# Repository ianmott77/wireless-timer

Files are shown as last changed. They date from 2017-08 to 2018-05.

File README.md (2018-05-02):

###### Author: Ian Mott

# Wireless Timer
This project aims at making a portable wireless timing system that's primary use is for athletics. The project's main sport of focus to start is alpine ski racing. 
 # Contents
 1. [Sports](#sports)
 2. [Features](#features)
 3. [Video](#video)
 4. [Things to know](#things-you-should-know-before-continuing-with-setup)
 5. [Hardware](#hardware)
 6. [Software](#software)
 7. [Usage](#using-the-wireless-timer)
 8. [Screenshots](#screenshots)
 
 # Sports
 ## Alpine Ski Racing
 In alpine ski racing a racer starts at the top of a race and goes through a wand which starts their time and the finish is triggered when the race crosses the "eyes" at the bottom. Finish eyes traditionally use some form of LASER or light break beam. During training sessions some teams will use wireless timing systems which can do this task with no wired set up required. This is a great training tool as it can tell you who is going fastest and when people are improving, and most teams who have them are able to see more improvements. One issue with current systems is they are expensive, some of them are outdated and haven't been upgraded in decades, and many of them are not very user friendly. That’s why this project was born! The goal is to use Arduino's and Raspberry Pi's to create a wireless timer which is cheaper and aims at usability.

# Features 
* Wireless Timing via LoRa line of site up to 20km
* Start and Finish currently, plans to support monitor tablet and multiple intervals
* Pace Mode and Stopwatch Mode
* Finish line length of up to 40m
* Virtually unlimited number of people on the track at one time
* Virtually unlimited space for runs
* Resistive touch screen to be able to provide a user-friendly UI while still allowing use of gloves or hand protection

# Video
Below is a link to a YouTube video demonstrating simple usage and proof of work for the idea:
* https://youtu.be/bO8R6ozuvQg

# Things You Should Know Before Continuing with Setup
* How to solder
* Basic C/C++ programming knowledge would be an asset (e.g. loops, constants)
* Basic Knowledge of Linux systems (e.g. file system, terminal use)
* How to upload Arduino libraries
* How to import new Arduino libraries

# Hardware
The idea behind the hardware set up is that the Arduino is used for sensors for the outside world while the Raspberry Pi (RPi) is responsible for handling the display as well as doing the information processing and storing information. 
## Set Up
### Hardware Needed
#### For All Pieces
* Raspberry Pi Zero W (https://www.raspberrypi.org/products/raspberry-pi-zero-w/)
* Arduino UNO (https://store.arduino.cc/usa/arduino-uno-rev3)
* Waveshare 4inch HDMI LCD, 800×480, IPS (https://www.waveshare.com/4inch-HDMI-LCD.htm)
* Adafruit RFM95W LoRa Radio Transceiver Breakout - 868 or 915 MHz (https://www.adafruit.com/product/3072)
* 4-channel I2C-safe Bi-directional Logic Level Converter (https://www.adafruit.com/product/757)
* MCP3008 - 8-Channel 10-Bit ADC With SPI Interface (https://www.adafruit.com/product/856)
* PowerBoost 1000 Charger - Rechargeable 5V Lipo USB Boost @ 1A - 1000C (https://www.adafruit.com/product/2465)
* Lithium Ion Battery Pack - 3.7V 6600mAh (https://www.adafruit.com/product/353)
* MicroSD Card
* 100k resistor
* Momentary push button 
* Yellow LED
* Red LED
* Blue LED
* 4 x 10k resistor
* 3 x 4001N diode
* 3 x 330 Ohm resistor
* 2 x 6.8k resistor

#### Interval Only
* LIDAR-Lite v3 (https://www.sparkfun.com/products/14032)

#### Starter Only
* Magnetic contact switch (https://www.adafruit.com/product/375)

### Diagrams
If you look in the diagrams folder you will find fritzing diagrams of how the different pieces need to be set up. The RPi and Arduino are connected through two different connections, the serial pins (UART) and I2C.

#### Starter Set Up
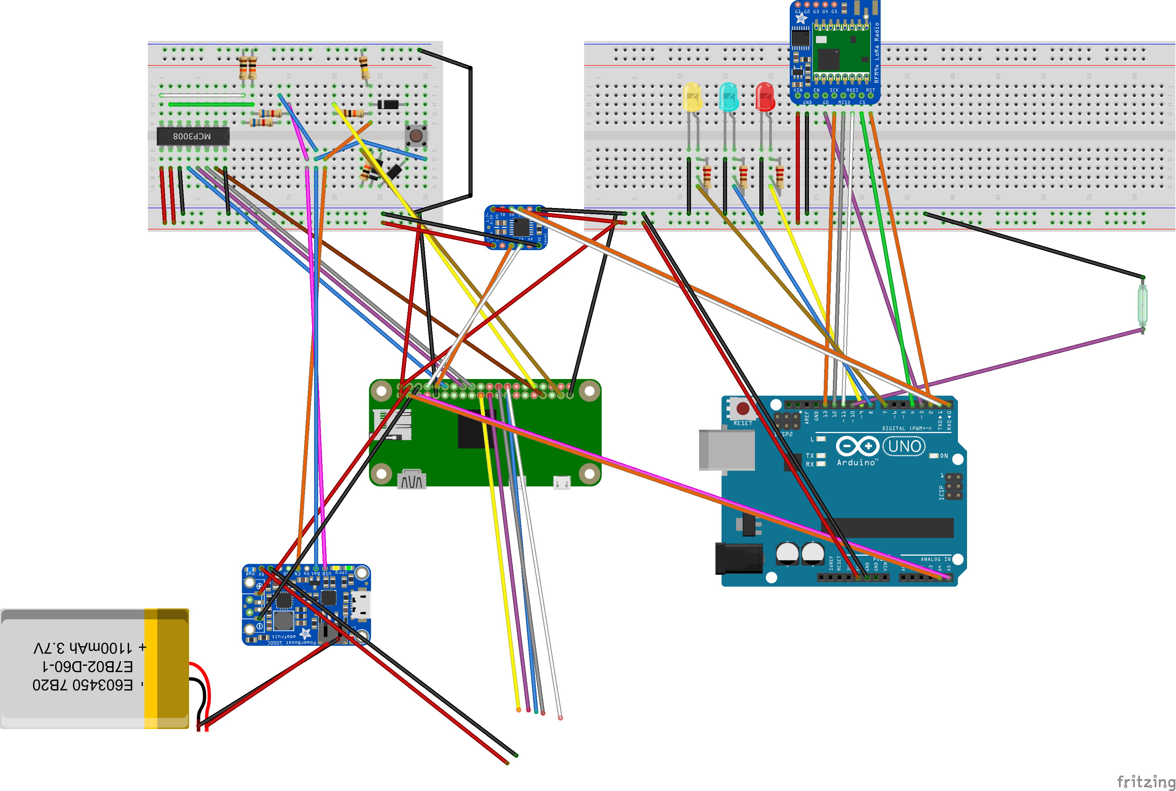
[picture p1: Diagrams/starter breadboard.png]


#### Finisher Set Up
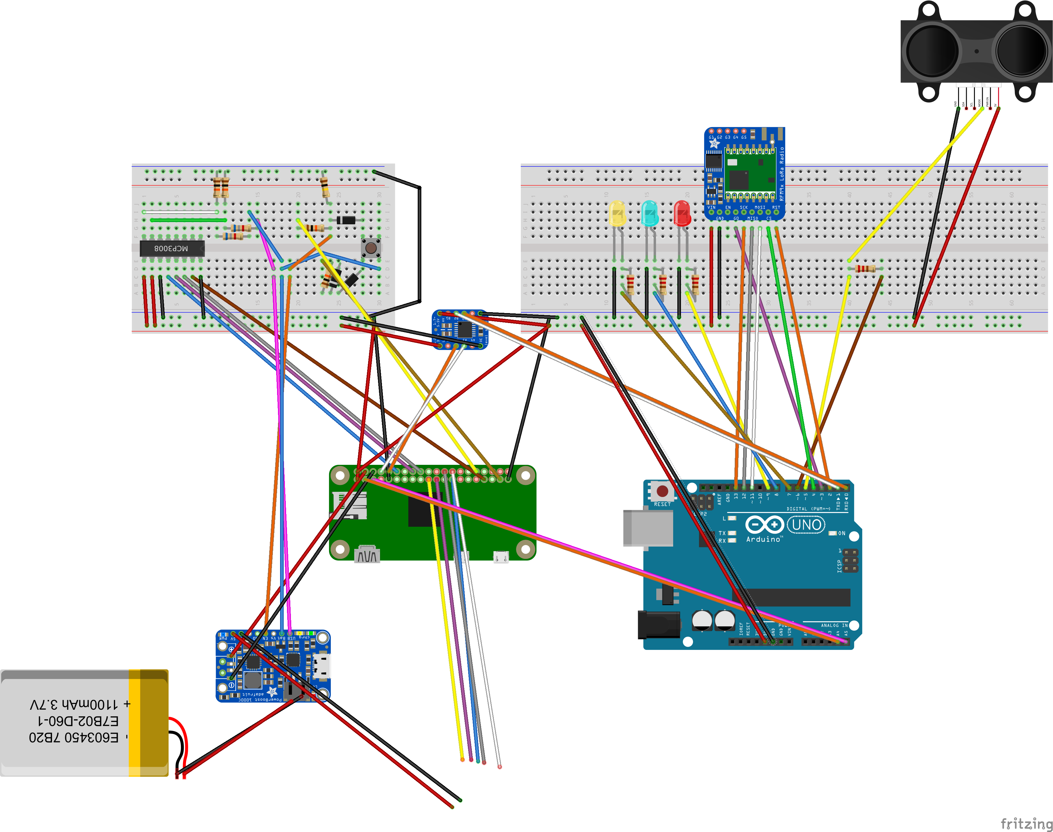
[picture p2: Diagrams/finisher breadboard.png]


##### Notes
* Where the wires disappear in the diagram is where they connect to a Waveshare 4" resistive touchscreen LCD
* In my set, up I used a 6600 mAH battery
* Yellow LED is the TX LED for the Arduino
* Blue LED is the RX LED for the Arduino
* Red LED is the error LED for the Arduino
* The LCD get's its own 5V power supply from the PowerBoost because it draws a large current and when it get's it's power from the rail on the breadboard I observed some flickering

# Software
## Repositories
All of them are required to run the WirelessTimer software, however for pi_power it is suggested that you use the script provided in this repository as it has been modified to accommodate the different battery voltage and different pins used.

### Raspberry Pi
* WirelessTimer: https://github.com/ianmott77/wireless-timer-rpi
* pi_power (modified): https://github.com/ianmott77/wireless-timer/blob/master/pi_power.py (Big thanks to @craic!! Original repo found here https://github.com/craic/pi_power)

### Arduino
* WirelessTimer: https://github.com/ianmott77/wireless-timer-arduino
* RadioHead: http://www.airspayce.com/mikem/arduino/RadioHead/
* LIDARLite V3: https://github.com/garmin/LIDARLite_v3_Arduino_Library

## Set Up
## Arduino
To set up the software for the Arduino start by downloading the WirelessTimer repo. The CLI folder contains the main program for the Arduino while the Connection folder contains the framework that it's built on. To install the program, add the Connection library, the RadioHead library and the LIDARLite V3 library to the Arduino software (instruction here: https://www.arduino.cc/en/hacking/libraries).

#### Device ID
Inside the repo you will also find a folder named "tools" inside this folder you will find a script name "WriteDeviceID" in order to set up the Arduino we need to write a Device ID to it's EEPROM which will be saved permanently and should be unique for all the timers in your network. If you open the script you will find a script like this
```
#include <EEPROM.h>
#define DEVICE_ID x

void setup(){
    EEPROM.write(0, DEVICE_ID);
}
void loop(){}
```
To write your desired unique device ID to the Arduino simply change where the "x" is to the unique device ID number you want and upload it to the Arduino. The device ID will be save permanently to the Arduino, after you run this script once you won't have to run it on an Arduino again unless you are changing its device type.

#### Device Type
Inside the repo you will also find a folder named "tools" inside this folder you will find a script name "WriteDeviceType" in order to set up the Arduino we need to write the device type to the Arduino. There are 3 different device types 

* 1 = Starter
* 2 = Interval (Finish Eyes)
* 3 = Monitor Node (not yet implemented)

```
#include <EEPROM.h>
#define DEVICE_TYPE x

void setup(){
    EEPROM.write(1, DEVICE_TYPE);
}
void loop(){}
```
To set the device type of the Arduino simply change the "x" in the script to the device type of you need and upload it to the Arduino. The device type will be save permanently to the Arduino, after you run this script once you won't have to run it on an Arduino again unless you are changing its device ID.

#### CLI
The final set up step for an Arduino is to upload the CLI script. Once you have done that the setup is complete. If everything is wired correctly you should see all three lights blink once, and nothing should be displayed on the serial monitor in the Arduino IDE if you have that open.

## Raspberry Pi
### Operating System
This project uses Raspbian Stretch Lite (https://www.raspberrypi.org/downloads/raspbian/) as it's base but requires several steps to set up. In future this will all be rolled in to a custom image but currently requires manual set up.
#### Configuring Raspbian
##### Downloading and setting up the MicroSD
To set up the Wireless timer software you first need to write the Raspbian Lite image to a micro SD card which is compatible with Raspberry Pi Zero W's (most micro SD's should work). If you're not sure how to do this, you can find detailed instructions here:

* https://www.raspberrypi.org/documentation/installation/installing-images/

To login the default username for the OS is "pi" and the default password is "raspberry"

#### Installing Display Drivers
The Waveshare screen should work with and HDMI connection from the RPi by default however the display may be the wrong orientation and it may be the wrong resolution, and the touch functionality won't work properly. You can follow the instructions found here:

* https://www.waveshare.com/wiki/4inch_HDMI_LCD

to setup the display properly. Once the drivers are installed you can test weather or not it is working with the program evtest. evtest is used to test input. It can be installed by typing```sudo apt-get install evtest``` and it can be run by typing ```evtest```. If you are not getting any input when touching the screen, check the connection and that you have the screen connected to the proper pins on the RPi.

#### Setting up pi_power
To set up pi power you can follow the instructions here however read bellow for the modifications made for this project:

* https://github.com/craic/pi_power

however, the script hosted in this repository is set up to use GPIO12 for boot up and GPIO13 to replace GPIO25, because GPIO25 is used by the touch screen, and the max and minimum voltages are adjusted for the battery I used.

In pi_power GPIO14 is used to power up the RPi because it goes high when booting up but goes low when powering down, however GPIO14 is the TX pin for the RPi and used by the Arduino to communicate. To accommodate this, we simulate GPIO12 going high when booting by using a custom device tree blob, detailed instructions on how to set this up can be found here: 

* https://www.raspberrypi.org/documentation/configuration/pin-configuration.md

to simulate GPIO12 going high when the RPi boot's we set it to output mode, and active. I have provided a dt-blob.dts in this repo which does that and should allow GPIO12 to be high after holding the momentary push button for a couple second and will go low when the RPi shuts down.

#### Setting up QT and EGLFS
Currently the only way to use this project is to build the WirelessTimer from scratch and currently the only host system tested so far is Ubuntu 17.10.

The Raspberry Pi portion of the project is based on QT. You can download QT for free here: 

* https://www.qt.io/download-qt-installer 

For the WirelessTimer program QT needs to be installed on the RPi's. Detailed instructions can be found here:

* https://wiki.qt.io/RaspberryPi2EGLFS

Note when setting up with a Raspberry Pi Zero or Zero W you will use the same compile commands as the Raspberry Pi 1. This process can take several hours so be patient and pay careful attention that you are doing the steps correctly. 

Once QT has been successfully installed the following QT modules also need to be installed:
* Qt Declarative (https://github.com/qt/qtdeclarative)
* Qt Quick Controls 2 (https://github.com/qt/qtquickcontrols2)
* Qt Quick Virtual Keyboard (https://github.com/qt/qtvirtualkeyboard) (not used currently but will be in future)

if you have followed all the instructions correctly you should have a kit setup where you can upload compiled Qt programs to your RPi.

# Using the Wireless Timer
If at any point you are not sure if you are on the right page you can refer to the screenshot section bellow to confirm.

### Import the project
To get started you first need to download the software here:
* https://github.com/ianmott77/wireless-timer-rpi
once it is downloaded you need to import it as project to Qt.

### Running the program
When the program runs you will notice the yellow and blue LED's blink frequently, this is because they blink every time there is an interaction either between the two Arduino's via LoRa or locally between the Arduino and the RPi. If the red LED blinks three times that means that is has hit an error, and which ever other LED is also lit while it's blinking indicates weather the error was while transmitting (yellow LED) or receiving (blue LED).

##### Setting the Finish
You will notice on interval pieces that the screen will automatically go the "Set Finish Distance" page. To set the distance, you simply click start and the LIDAR Lite will start measuring distances and reporting it back to the RPi. Point the LIDAR Lite at an object where you would like to line up your finish line and hit set. If you hit cancel if will set the distance to whatever it was set at last, if nothing was set then it will go back to 0.

#### Synchronizing Devices
On all device you will notice that there is a "Status" page. On the "Status" page you will see that there is both a "Position" and a "ID". The "Position" on all devices will default to 1, and the device ID of each device is set permanently by writing it to the EEPROM of the Arduino when you set it up. 

##### Position
Because the network is set up similarly to a doubly linked list(https://en.wikipedia.org/wiki/Doubly_linked_list), every device knows about the device that is at the position before it and the device that is at the next position. Because currently only a start and finish are supported there are only two positions that are relevant:
1: Start
2: Finish
and because currently you are always adding the finish from the start you always want the position you are adding to be 2.

##### Device ID
This is the device ID you specified when setting up the Arduino. This can be found on the status page of the finish device.

To synchronize the device, enter the position you want to add to the network (2) and the device ID of the device you want to add. For example, if I had a Start piece which had the ID=4, and a finish piece with the ID=9, on the "Add Device" page I would want to tap the text box I want to edit and for "Device Position:" I would enter 2, and for "Device ID" I would enter 9.

Once the sync is complete you will notice that in the status bar of both devices that the red circle next to "Sync:" are now green. This indicates that the sync was successful.

#### Selecting a Mode
The WirelessTimer software offers different modes in which to time, currently it offers stopwatch mode, and pace mode. On the "Mode Select Page" you will find a button for both options, and if you go to the "Options" page you will find a button "Select Mode" which allows you to return to the "Mode Select" page if you would like to switch from one mode to the other.

##### Stopwatch
This mode is the most basic mode in which to time. The times start as soon as the magnetic contact opens and will stop when something makes the LIDAR Lite pick up a distance less then 15cm of what the finish distance was set to. You also have the option to manually DNF (Did Not Finish) the racer as well if they won’t be completing the run. This mode allows for as many people on course as you would like and will not automatically DNF anyone.

##### Pace
In pace mode a reference time is used to determine weather or not something crossing the finish line is likely to be the thing we expect to be crossing the line. Currently the threshold to test against the pace time is 10 seconds. For example if you select pace mode the first person to go down the course will have their finish time recorded as the pace time, and from then on when someone starts the time any thing that triggers the finish which is 10 seconds faster than the pace time will not trigger the finish, and if the time goes more then 10 seconds over the pace time then the finish will automatically trigger a DNF.

#### Starting a racer
Once you know which mode you would like and select that button a keyboard will appear with a text box above it. The text box holds the bib number of the racer about to start and defaults to 1. If the start is not synchronized the "Okay" button will be grey and disabled, if it is green the it is ready to go!

##### Stopwatch Mode
In stopwatch mode it is very straight forward you simply enter a bib number, hit "Okay" and open the magnetic contact switch and the time will be started. You can do as many racers on the track at one time as you would like.

##### Pace Mode
In pace mode you will enter the number of the bib you would like to, hit "Okay", and then open the magnetic contact switch, however in pace mode if there is no pace time set then the start will stay with the "Ready!" page with a loading indicator bellow it until the racer completes there run, at which point the time of the racer will be transmitted back to the start, and from then on the pace will be set at the first runners time, and the threshold will be 10 seconds. If the person setting the pace does not complete their run you can manually click "DNF" on the finish piece which will let the start know that a pace wasn't set and then the next racer will set the pace.

# Screenshots
#### Mode Select
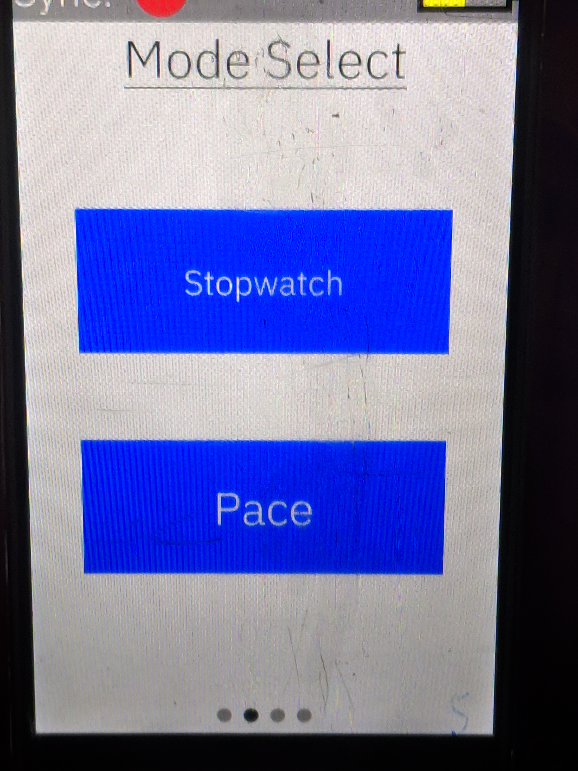
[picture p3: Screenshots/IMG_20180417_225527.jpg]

#### Set Finish Distance
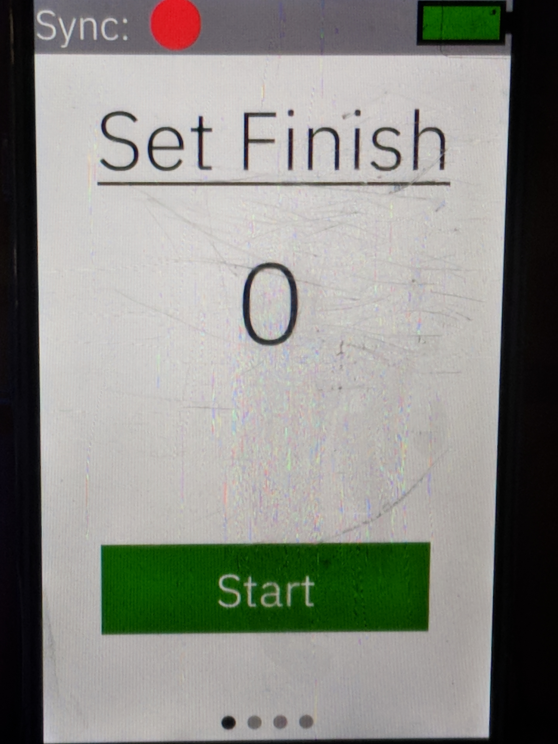
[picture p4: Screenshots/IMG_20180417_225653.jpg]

#### Choose Bib Number
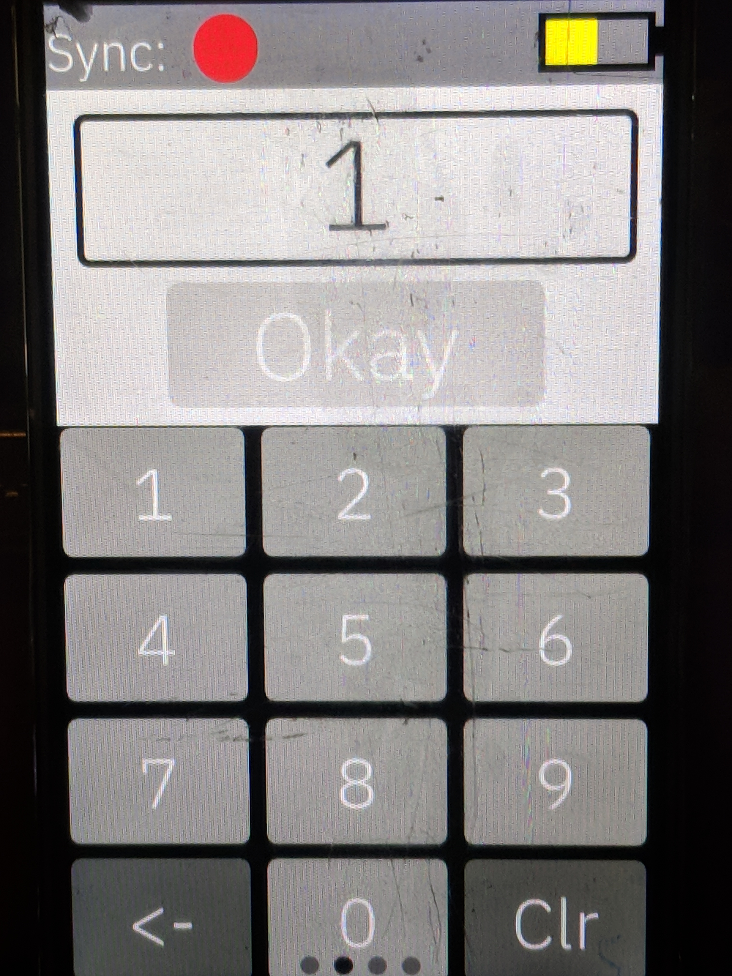
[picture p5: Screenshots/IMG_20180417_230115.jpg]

#### Status
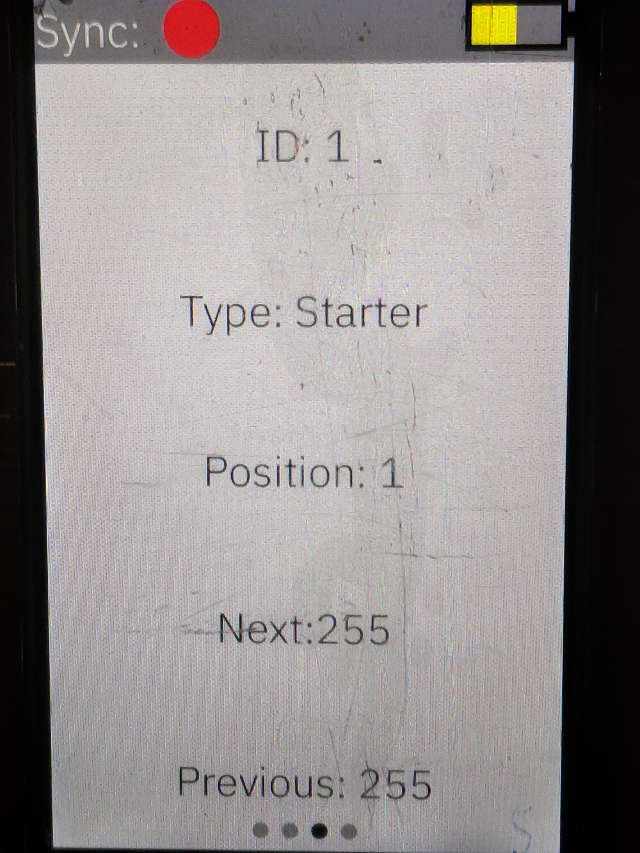
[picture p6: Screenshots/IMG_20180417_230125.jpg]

#### Add Device
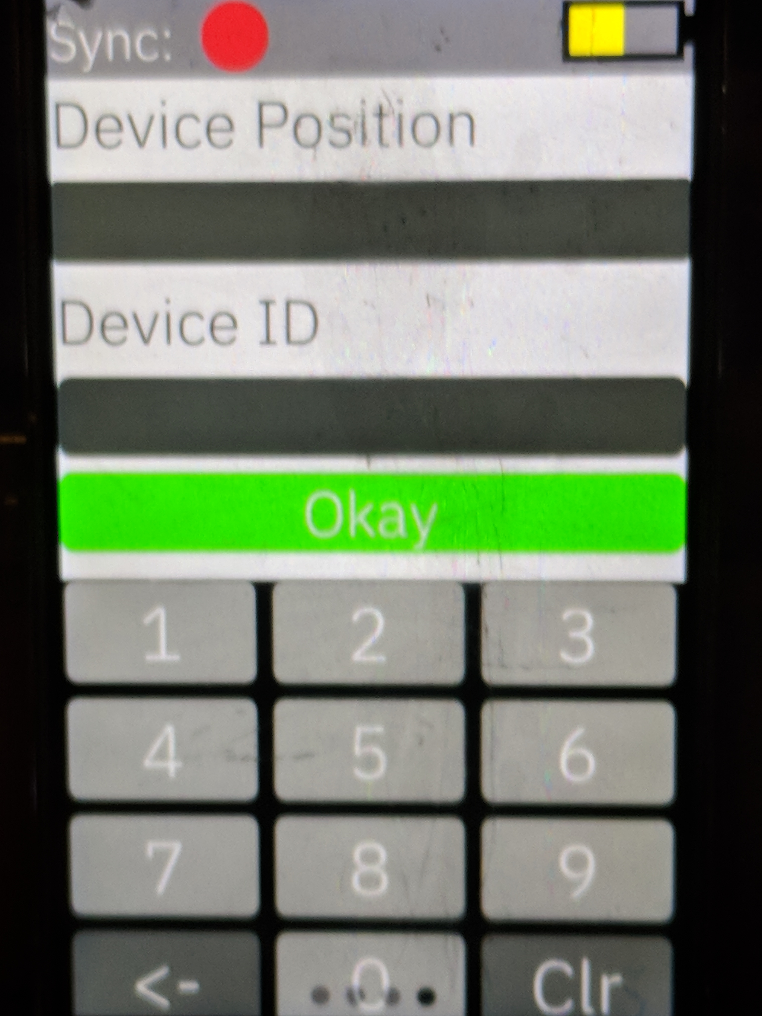
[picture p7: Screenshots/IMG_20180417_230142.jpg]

#### Options
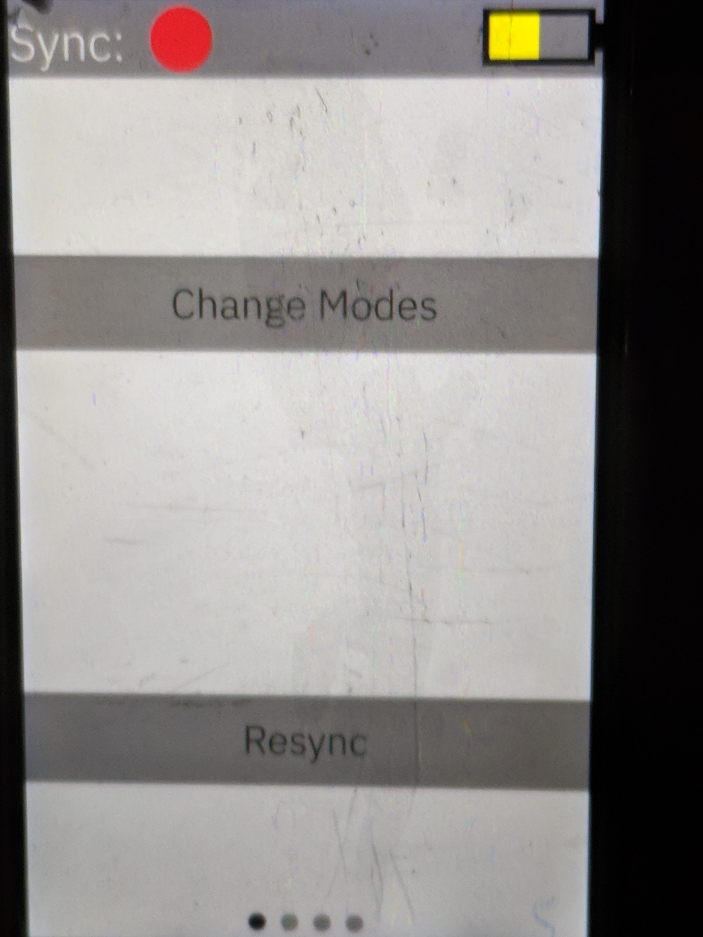
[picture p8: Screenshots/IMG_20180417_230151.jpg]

#### Time of Next to Finish
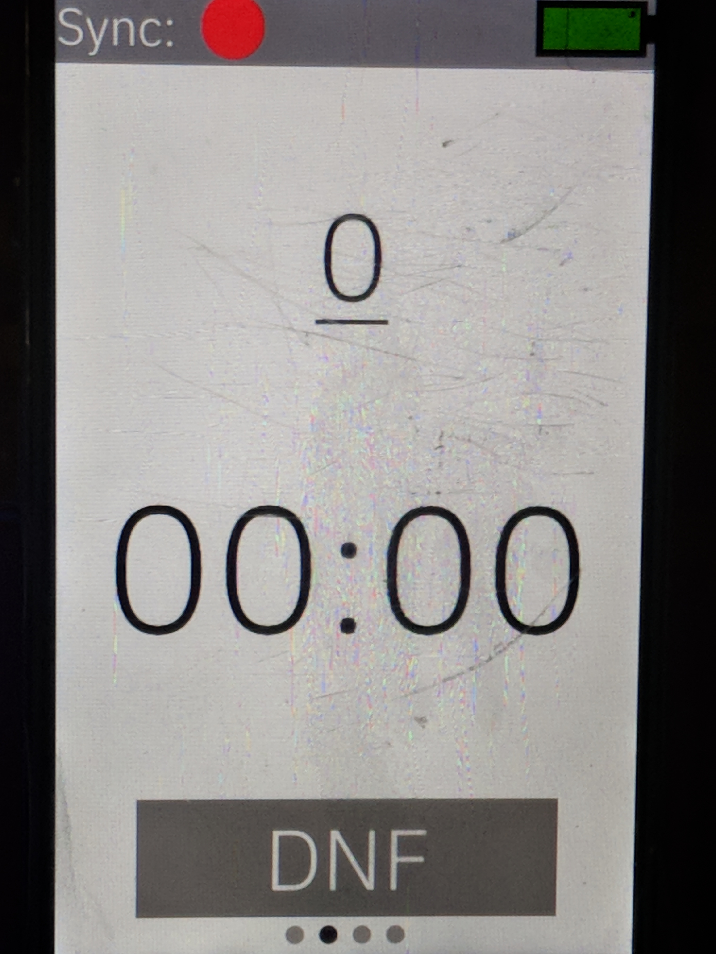
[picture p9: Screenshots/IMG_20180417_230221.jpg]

#### View All Times
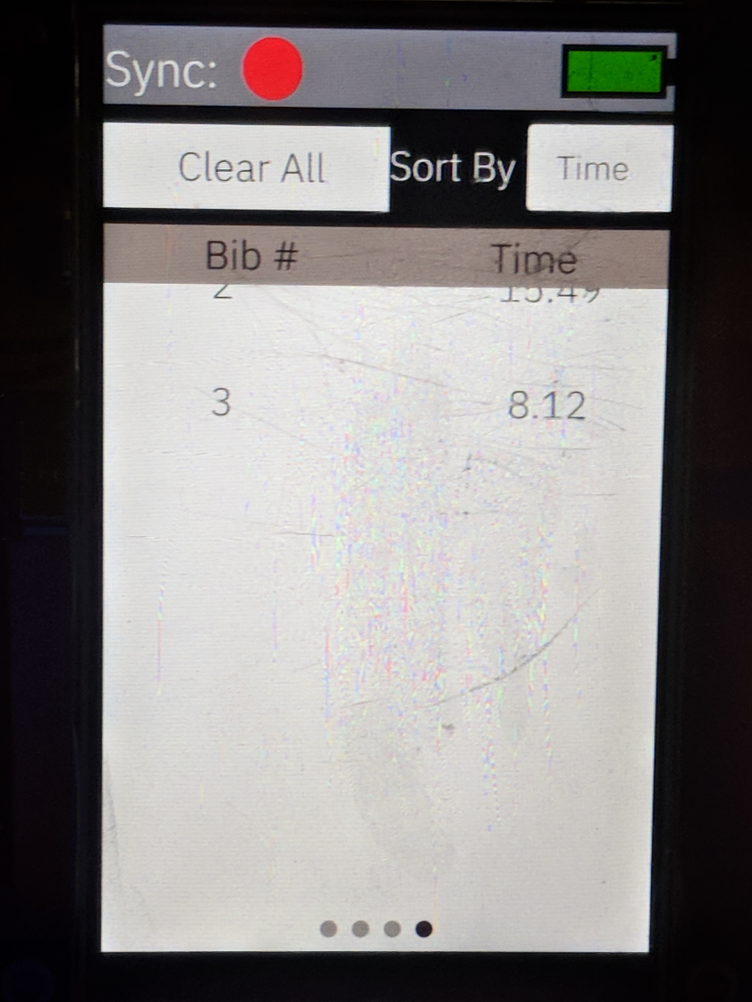
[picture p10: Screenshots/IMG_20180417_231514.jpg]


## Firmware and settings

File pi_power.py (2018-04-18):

#!/usr/bin/env python

# pi_power.py

# Robert Jones 2016 jones@craic.com

# The code for reading the MCP3008 analog to digital convertor (readadc) was
# written by Limor "Ladyada" Fried for Adafruit Industries, (c) 2015
# This code is released into the public domain


# Works with an Adafruit PowerBoost 1000C LiPo battery charger

# Writes the fraction of battery remaining as well as the current power source to the file /home/pi/.pi_power

# format:  <float 0.00 - 1.00>,<string [battery|usb]>
# 0.75,battery
# 1.00,usb



import time
import os
import argparse
import RPi.GPIO as GPIO


# read SPI data from MCP3008 chip, 8 possible adc's (0 thru 7)
def readadc(adcnum, clockpin, mosipin, misopin, cspin):
        if ((adcnum > 7) or (adcnum < 0)):
                return -1
        GPIO.output(cspin, True)

        GPIO.output(clockpin, False)  # start clock low
        GPIO.output(cspin, False)     # bring CS low

        commandout = adcnum
        commandout |= 0x18  # start bit + single-ended bit
        commandout <<= 3    # we only need to send 5 bits here
        for i in range(5):
                if (commandout & 0x80):
                        GPIO.output(mosipin, True)
                else:
                        GPIO.output(mosipin, False)
                commandout <<= 1
                GPIO.output(clockpin, True)
                GPIO.output(clockpin, False)

        adcout = 0
        # read in one empty bit, one null bit and 10 ADC bits
        for i in range(12):
                GPIO.output(clockpin, True)
                GPIO.output(clockpin, False)
                adcout <<= 1
                if (GPIO.input(misopin)):
                        adcout |= 0x1

        GPIO.output(cspin, True)
        
        adcout >>= 1       # first bit is 'null' so drop it
        return adcout


# Calculate the output of a voltage divider
# voltage_divider layout is:
# Vin ---[ R1 ]---[ R2 ]---GND
#               |
#              Vout
#
# Vout = R2 / (R1 + R2) * Vin
# e.g. if R1 = 6800 and R2 = 10000 and Vin is 5.2V then Vout is 3.095
#
def voltage_divider(r1, r2, vin):
        vout = vin * (r2 / (r1 + r2))
        return vout



# Set up a trigger to shutdown the system when the power button is pressed
# define a setup routine and the actual shutdown method

# The shutdown code is based on that in https://github.com/NeonHorizon/lipopi

def user_shutdown_setup(shutdown_pin):
    # setup the pin to check the shutdown switch - use the internal pull down resistor
    GPIO.setup(shutdown_pin, GPIO.IN, pull_up_down=GPIO.PUD_DOWN)

    # create a trigger for the shutdown switch
    GPIO.add_event_detect(shutdown_pin, GPIO.RISING, callback=user_shutdown, bouncetime=1000)

# User has pressed shutdown button - initiate a clean shutdown
def user_shutdown(channel):
    global safe_mode
        
    shutdown_delay = 10 # seconds

    # in Safe Mode, wait 2 mins before actually shutting down
    if(safe_mode):
        cmd = "sudo wall 'System shutting down in 2 minutes - SAFE MODE'"
        os.system(cmd)
        time.sleep(120)

    cmd = "sudo wall 'System shutting down in %d seconds'" % shutdown_delay
    os.system(cmd)
    time.sleep(shutdown_delay)

    # Log message is added to /var/log/messages
    os.system("sudo logger -t 'pi_power' '** User initiated shut down **'")
    GPIO.cleanup()
    os.system("sudo shutdown now")


# Shutdown system because of low battery
def low_battery_shutdown():
    global safe_mode

    shutdown_delay = 30 # seconds
    
    # in Safe Mode, wait 2 mins before actually shutting down
    if(safe_mode):
        cmd = "sudo wall 'System shutting down in 2 minutes - SAFE MODE'"
        os.system(cmd)
        time.sleep(120)
    
    cmd = "sudo wall 'System shutting down in %d seconds'" % shutdown_delay
    os.system(cmd)
    time.sleep(shutdown_delay)
    # Log message is added to /var/log/messages
    os.system("sudo logger -t 'pi_power' '** Low Battery - shutting down now **'")
    GPIO.cleanup()
    os.system("sudo shutdown now")
                

    

# MAIN -----------------------

GPIO.setwarnings(False)
GPIO.setmode(GPIO.BCM)

# Command Line Arguments
# --log    write time, voltage, etc to a log file
# --debug  write time, voltage, etc to STDOUT

parser = argparse.ArgumentParser(description='Pi Power - Monitor battery status on RasPi projects powered via Adafruit PowerBoost 1000C')

parser.add_argument('-d', '--debug', action='store_true')
parser.add_argument('-l', '--log',   action='store_true')
parser.add_argument('-s', '--safe',  action='store_true')

args = parser.parse_args()

safe_mode = False
if(args.safe):
        safe_mode = True

        
# Setup the GPIO pin to use with the use shutdown button

user_shutdown_pin = 26
user_shutdown_setup(user_shutdown_pin)


# Setup the connection to the ADC

# specify the Raspberry Pi GPIO pins to be used to connect to the SPI interface on the MCP3008 ADC

SPICLK  = 18
SPIMISO = 23
SPIMOSI = 24
SPICS   = 13

# set up the SPI interface pins
GPIO.setup(SPIMOSI, GPIO.OUT)
GPIO.setup(SPIMISO, GPIO.IN)
GPIO.setup(SPICLK,  GPIO.OUT)
GPIO.setup(SPICS,   GPIO.OUT)

# Vbat to adc #0, Vusb connected to #1
v_bat_adc_pin = 0
v_usb_adc_pin = 1

# Voltage divider drops the PowerBoost voltage from around 5V to under 3.3V which is the limit for the Pi
voltage_divider_r1 =  6800.0
voltage_divider_r2 = 10000.0

# Define the min and max voltage ranges for the inputs

usb_min_voltage = 0.0
usb_max_voltage = 5.2

gpio_min_voltage = 0.0
gpio_max_voltage = 3.3

# LiPo battery voltage range - actual range is 3.7V to 4.2V
# But in practice the measured range is reduced as Vbat always drops from 4.2 to around 4.05 when the
# USB cable is removed - so this is the effective range:

battery_min_voltage = 3.00
battery_max_voltage = 3.75

# this is the effective max voltage, prior to the divider, that the ADC can register
adc_conversion_factor = (gpio_max_voltage / voltage_divider(voltage_divider_r1, voltage_divider_r2, usb_max_voltage)) * usb_max_voltage


pi_power_status_path = '/home/pi/.pi_power_status'
pi_power_log_path    = '/home/pi/pi_power_log.csv'


# initialize an empty log file
if(args.log):
        with open(pi_power_log_path, "w") as f:
                f.write('Time,Vbat,Vusb,Frac,Source\n')


# Take a measurement every poll_interval * seconds * - default 60
poll_interval = 5

power_source = ''
power_source_previous = ''

fraction_battery = 1.0

# Define the minimum battery level at which shutdown is triggered

fraction_battery_min = 0.075


if(args.debug):
        print 'Time    Vbat   Vusb   Frac   Source'


elapsed_time = 0
msg = ''

while True:
        # read the analog pins on the ACD (range 0-1023) and convert to 0.0-1.0
        frac_v_bat = round(readadc(v_bat_adc_pin,   SPICLK, SPIMOSI, SPIMISO, SPICS)) / 1023.0
        frac_v_usb = round(readadc(v_usb_adc_pin,   SPICLK, SPIMOSI, SPIMISO, SPICS)) / 1023.0
       
        # Calculate the true voltage
        v_bat = frac_v_bat * adc_conversion_factor
        v_usb = frac_v_usb * adc_conversion_factor
                       

        fraction_battery = (v_bat - battery_min_voltage) / (battery_max_voltage - battery_min_voltage)

        if fraction_battery > 1.0:
               fraction_battery = 1.0
        elif fraction_battery < 0.0:
               fraction_battery = 0.0

        
        # is the USB cable connected ? Vusb is either 0.0 or around 5.2V       
        if v_usb > 1.0:
                power_source = 'usb'
        else:
                power_source = 'battery'

        if power_source == 'usb' and power_source_previous == 'battery':
                print '** USB cable connected'
        elif power_source == 'battery' and power_source_previous == 'usb':
                print '** USB cable disconnected'

        power_source_previous = power_source

        msg = ''
        # If battery is too low then shutdown
        if fraction_battery < fraction_battery_min:
               msg = 'Low Battery - shutdown now'
               if(args.debug):
                       print "** LOW BATTERY - shutting down........"
               # shutdown after writing to the log file

        if(args.debug):
                print '{0:6d}  {1:.3f}  {2:.3f}  {3:.3f}  {4:s}  {5:s}'.format(elapsed_time, v_bat, v_usb, fraction_battery, power_source, msg)

        # Open log file, write one line and close
        # This handles the case where the battery is allowed to drain completely and 
        # shutdown in which case the file may be corrupted
        if(args.log):
                with open(pi_power_log_path, "a") as f:
                        f.write('{0:d},{1:.3f},{2:.3f},{3:.3f},{4:s},{5:s}\n'.format(elapsed_time, v_bat, v_usb, fraction_battery, power_source, msg))

        # Write the .pi_power status file - used by pi_power_leds.py
        with open(pi_power_status_path, "w") as f:
                f.write('{0:.3f},{1:s}\n'.format(fraction_battery,power_source))

        # Low battery shutdown - specify the time delay in seconds
        if fraction_battery < fraction_battery_min:
                low_battery_shutdown()
        
        # sleep poll_interval seconds between updates
        time.sleep(poll_interval)

        elapsed_time += poll_interval

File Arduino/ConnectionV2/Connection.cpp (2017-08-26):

#include "Connection.h"
#include <MemoryFree.h>
#define OUT 7
#define IN 8
void m(){
    Serial.print("mem=");
    Serial.println(freeMemory());
    Serial.flush();
}

void wireReceiver(int bytes){
    if(!blocking){
        accept();
    }else if(currentConnection == I2){
        accept();
    } 
}

void sendWire(){
    if(!blocking){
        transmit();
    }else if(currentConnection == I2){
        transmit();
    }
}

void setNextAddress(uint8_t next){
    _next_address = next;
}

void setThisAddress(uint8_t t_address){
    _this_address = t_address;
    if(manager != '\0')
        manager->setThisAddress(_this_address);
}

bool switchTo(Connection c){
    currentConnection = c;
    pinMode(IN, OUTPUT);
    pinMode(OUT, OUTPUT);
    if(currentConnection == I2){
        Wire.begin(SLAVE_ADDRESS);
        Wire.setClock(400000);
        Wire.onReceive(wireReceiver);
        Wire.onRequest(sendWire); 
    }else if(currentConnection == LORA){

        if(driver == '\0'){
            driver = new RH_RF95(RFM95_CS, RFM95_INT);
        }
        
        if(manager == '\0' && driver != '\0'){
            manager = new RHReliableDatagram(*driver, _this_address);
            if (!manager->init()){
                return false;
            }
        }
       
        driver->setTxPower(23, false);
    }
    return true;
}

void setHandlers(receivePack r, sendMessage s){
    afterPackCreation = r;
    beforePackCreation = s;
}

void setReceiveHandler(receivePack r){
    afterPackCreation = r;
}

void setSendHandler(sendMessage s){
    beforePackCreation = s;
}

void setSendCallback(func f){
    sendCallback = f;
}

void setReceiveCallback(func f){
    receiveCallback = f;
}

void setBlocking(bool val){
    blocking = val;
}

char read(){
    if(currentConnection == I2){
        return Wire.read();
    }else if(currentConnection == SER){
        return Serial.read();
    }else if(currentConnection == SPIC){
    
    }
}

int write(char data){
    if(currentConnection == I2){
        return Wire.write(data);
    }else if(currentConnection == SER){
        int n = Serial.write(data);
        Serial.flush();
        return n;
    }else if(currentConnection == SPIC){
    }else if(currentConnection == LORA){
        return manager->sendtoWait(data, sizeof(data), _next_address);
    }
}

int write(uint8_t * buf, int size){
    if(currentConnection == I2){
        return Wire.write(buf, size);;
    }else if(currentConnection == SER){
        int n = Serial.write(buf, size);
        Serial.flush();
        return n;
    }else if(currentConnection == SPIC){
        
    }else if(currentConnection == LORA){
        if(manager->sendtoWait(buf, size, _next_address)){
            return size;
        }
        return 0;
    }
}

int available(){
    if(currentConnection == I2){
        return Wire.available();    
    }else if(currentConnection == SER){
        return Serial.available();
    }else if(currentConnection == SPIC){
        
    }else if(currentConnection == LORA){
        return (int) manager->available();
    }
}

bool send(int data){
    uint8_t * buf = (uint8_t*) malloc(2);
    buf[0] = data >> 8;
    buf[1] = data & 0xFF;
    if(write(buf, 2) == 2){
        delete buf;
        buf = '\0';
        return true;
    }
    delete buf;
    buf = '\0';
    return false;
}

bool send(long data){
    uint8_t * buf = (uint8_t*) malloc(4);
    buf[0] = data & 0xFF;
    for(int i = 1; i < 4; i++)
        buf[i] = (data >> (i*8)) & 0xFF;
    if(write(buf, 4) == 4){
        delete buf;
        buf = '\0';
        return true;
    }
    delete buf;
    buf = '\0';
    return false;
}

bool send(unsigned long data){
    uint8_t * buf = (uint8_t*) malloc(4);
    buf[0] = data & 0xFF;
    for(int i = 1; i < 4; i++)
        buf[i] = (data >> (i*8)) & 0xFF;
    if(write(buf, 4) == 4){
        delete buf;
        buf = '\0';
        return true;
    }
    delete buf;
    buf = '\0';
    return false;
}


bool send(char * data){
    if(currentConnection != LORA){
        for(int i = 0; i < strlen(data); i++){
            if(!write(data[i]))
                return false;
        }
    }else{
        if(!manager->sendtoWait(data, sizeof(data), _next_address)){
           return false; 
        }
    }
    return true;
}

int readInt(){
    int r = NULL;
    if(currentConnection != LORA){
        if(available() >= 2){
            r = read() << 8;
            r |= read() & 0xFF;
        }
    }else{
        uint8_t * buf = malloc(2);
        uint8_t * len = malloc(2);
        uint8_t l = 2;
        memcpy(len, &l, 2);
        uint8_t  * from = malloc(2);
        if (manager->recvfromAck(buf, len, from)){
            r = buf[0] << 8;
            r |= buf[1] & 0xFF;
        }else{
            Serial.println("receive Failed");
        }
        delete buf;
        delete len;
        delete from;
    }
    return  r;
}

long readLong(){
    if(currentConnection != LORA){
        union{
            uint8_t buf[4];
            long val;
        } long_union;
        
        for(int i = 0; i < 4; i++){
            long_union.buf[i] = read();
        }
        return long_union.val;
    }else{
        uint8_t * buf = (uint8_t*) malloc(4);
        uint8_t * len = malloc(2);
        uint8_t r = 4;
        memcpy(len, &r, sizeof(r));
        uint8_t * from = malloc(2);
        
        if (!manager->recvfromAck(buf, len, from)){
            delete buf;
            delete len;
            delete from;
            return NULL;
        }
        long val = (buf[3] << 24) | (buf[2] << 16) | (buf[1] << 8) | buf[0];
        delete buf;
        delete len;
        delete from;
        
        return val;
    }
}

unsigned long readULong(){
    if(currentConnection != LORA){
        union{
            uint8_t buf[4];
            unsigned long val;
        } long_union;
        
        for(int i = 0; i < 4; i++){
            long_union.buf[i] = read();
        }
        return long_union.val;
    }else{
        uint8_t * buf = malloc(4);
        uint8_t * len = malloc(2);
        uint8_t r = 4;
        memcpy(len, &r, sizeof(r));
        uint8_t * from = malloc(2);
        
        if (!manager->recvfromAck(buf, len, from)){
            delete buf;
            delete len;
            delete from;
            return NULL;
        }
        unsigned long val = (buf[3] << 24) | (buf[2] << 16) | (buf[1] << 8) | buf[0];
        delete buf;
        delete len;
        delete from;
        
        return val;
    }
}
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

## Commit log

2017-05-21 This is the first commit for the wireless timer project. This is the connection library which will be used to communicate between Arduino and Raspberry Pi. This commit only supports i2c, however the 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
2017-05-21 Added examples for I2C connection
2017-05-21 updated Arduino Example with comments for clarity
2017-05-29 Updates
    -removed unnecessary functions form I2C object and from Packet
    -fixed receive function to have proper order
    -no leaks
2017-05-29 -updates fixes control flow of receive
    [Connection.cpp]
2017-05-29 -fixed deletes of strings
    [Connection.cpp]
2017-05-29 -removed unnecessary variables -fixed style
    [Connection.cpp]
2017-08-26 Proper upload
    -last one was the wrong files
    [Connection.cpp]
2017-08-26 Updated Sync 1
    -updated now works properly no memory leaks
    [LoRa_test_1.ino]
2017-10-23 major updates
    now includes working timing with reed switch attached to pin 10 on
    Arduino, also now includes working distance reading from LIDARLite V3
2018-01-23 Fritzing Diagarams
    Added Fritzing diagrams for stater, finisher and generic timing node
    [Finisher.fzz, Starter.fzz, WirlessTimer Node.fzz]
2018-04-17 Add files via upload
    Added battery component to diagram
    [Starter with Battery.fzz, Timer with Battery.fzz]
2018-04-17 Add files via upload
    -made fix to wiring of voltage converter
    [Finisher.fzz, Starter.fzz]
2018-04-18 Added custom device tree blob and added modified pi_power.py script
